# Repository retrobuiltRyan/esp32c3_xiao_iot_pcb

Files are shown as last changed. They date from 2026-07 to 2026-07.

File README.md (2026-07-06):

# esp32c3_xiao_iot_pcb
PCB for MQTT projects. Sensor, I2C screen, rotary encoder input, RGB LEDs, and buck converter breakout for the ESP32 C3 XIAO dev board.

| Project Difficulty | Rating |
|---|---|
| **Hardware Difficulty** | ●● Easy |
| **Software Complexity** | ●● Easy? | 

PCB <br>
This is the ~$5 [ESP32c3 XIAO microcontroller](https://www.digikey.com/en/products/detail/seeed-technology-co-ltd/113991054/16652880) (with its antenna on the left) variant.

P1130036

### Example Projects

Three-ish example projects are shown using this PCB:

- 1.1 – WiFi Clock
- 1.2 – Basic "Dumb" Clock
- 1.3 – Countdown Timer
- 2.0 – Weather Station with Terminal-Style Display
- 3.0 – Current (120V AC) Probe Monitor over MQTT

## 1.1 WiFi Clock
P1130023 <br>
P1130020 <br>

Large digit (70mm height) 7-segment clock. Connects to 2.4 GHz WiFi and grabs time from HTTP "google.com" TCP port 80. Previously grabbed time from NTP, but I have found some enterprise networks do not like this traffic and block the device.  

Files for the [RGB LED 7-segment digit PCB](https://github.com/retrobuiltRyan/Neo7Segment-Design-Files). You'll need to make four (each digit needs qty 29 RGB LEDs).  

A Daylight Saving Time function is implemented; however, every 6 months I find this doesn't work as expected, and 6 months between bug testing is annoying, so YMMV. DST compensation works better on Network Time Protocol grabs, but again, some networks do not like this.  

The body is 3D printed. The digit diffusion layer can be experimented with in material color and thickness. (about 0.2)

## 1.2 Dumb Clock (no WiFi)
P1130025 <br>

Same hardware, different code for a regular clock that keeps time without WiFi. Hours and minutes are set using the rotary encoder & push button.  

UI Flow:  
BOOT → SET HOURS → SET MINUTES → SET COLOR → RUN  
While in RUN → (press) BRIGHTNESS → Return  
Long press resets clock to 12:00  

## 1.3 Countdown Timer
Task Master style countdown timer. 
UI Flow:
BOOT → brightness adjust + pulsing 00:00 →press [set min] press→ [set hr] →press [start]
Time starts out green color and gradually changes to red as 00:00 time approaches.

## 2.0 Weather Station
P1130031 <br>

Calls API: https://api.weather.gov/points/40.4406,-79.9959. Then grabs weather forecast data from https://api.weather.gov/gridpoints/PBZ/78,66/forecast. A bunch of forecast data is returned in JSON text format.  The lat and long point to Pittsburgh, PA, which can be changed. This weather API is a free government service available in the USA only, one benefit is no need for API key. Code then parses only the first five forecast 'periods' to save SRAM and prints over serial (for debug) and to OLED in a terminal-style display using this [2.4 inch OLED screen](https://www.aliexpress.us/item/3256805914521312.html).  
Forecast updates every hour. 3D printed body is stylized as a classic Mac if it was extra wide.  

## 3.0 Current Probe Monitor over MQTT
P1130028 <br>
(add a dashboard pic when I get that done) <br>

It's lunchtime and you're starving, but there might be a line for the microwave and toaster! Three minutes for someone's Factor meal to cook?! Wouldn't you like to know if these appliances are available before walking to the office kitchen? What if you could check a dashboard that monitors microwave and toaster oven usage?  

Two contactless probes (current clamp) monitor current draw (0–10A) of both appliances and report their status over MQTT. A dashboard logs usage history and can provide a bunch of interesting data on office lunchtime habits. Could also be deployed as an online monitor for critical infrastructure like deep freezers or coolant pumps—useful things. A temperature and humidity sensor (SHT45) is populated on this PCB to also report ambient conditions as a baseline data point. The SHT45 is a very tiny SMD part; adding this is advanced soldering (you need that stencil ordered).

## PCB BoM
| Reference | Value | Qty | DigiKey P/N |
|---|---|----:|---|
| BZ1 | Buzzer_5V | 1 | |
| C1, C3, C4, C5, C6, C8, C10 | 0.1uF 50V | 7 | 1276-1068-1-ND |
| C2, C7, C9, C11 | 0.22uF 50V CER | 4 | 445-2283-1-ND |
| D1 | WS2812B | 1 | [aliexpress](https://www.aliexpress.us/item/3256802466699315.html) |
| D5, D6, D7 | LED | 3 | 1080-1419-1-ND |
| D8 | D | 1 | S5AC-FDICT-ND |
| D9 | SMF15A | 1 | SMF15A-E3-08CT-ND |
| J1 | Barrel_Jack 2.1 × 5.5mm | 1 | EJ508A-ND |
| J2, J5, J6, J7, J10 | Screw_Terminal_2_P3.50mm | 5 | 732-2747-ND |
| Q1 | MOSFET P-CH 30V 25A TO252 | 1 | 785-1106-1-ND |
| Q2 | MMBT2222A | 1 | MMBT2222ATPMSCT-ND |
| Q3 | AO3400A | 1 | 785-1000-1-ND |
| R1 | 220 | 1 | 311-220FRCT-ND |
| R2, R3, R5, R6 | 1K | 4 | 311-1.00KFRCT-ND |
| R4 | 3.3K | 1 | 311-3.30KFRCT-ND |
| R7 | 100k | 1 | 311-100KFRCT-ND |
| R8, R9 | 10K | 2 | 311-10.0KFRCT-ND |
| RN1 | 10k array | 1 | CAY16-103J4LFCT-ND |
| RN4 | 200 array | 1 | CAY16-201J4LFCT-ND |
| SW1 | RotaryEncoder_Switch_MP | 1 | PEC11R-4220F-S0024-ND |
| U1 | MAX40200AUK | 1 | 175-MAX40203AUK+TCT-ND |
| U2 | MP1584_Buck | 1 |[aliexpress](https://www.aliexpress.us/item/3256805684077964.html) |
| U3 | L7805 | 1 | 497-7255-1-ND |
| U7 | ESP32C3 | 1 | 1597-113991054-ND |
| U8 | UCC27511ADBV | 1 | 296-49474-1-ND |
| U9 | SHT4x | 1 | 1649-SHT45-AD1B-R2CT-ND |

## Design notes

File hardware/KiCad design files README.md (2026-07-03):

Place all three kicad files (.kicad_pcb, .kicad_sch, .kicad_pro) in a folder of the same name. Open the project file (.kicad_pro) with KiCad.
PCB

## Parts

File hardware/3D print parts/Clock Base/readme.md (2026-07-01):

3D printed body for Clock.
P1130021

print preview
P1130025

Change the z-scaling of the diffuser for the desired effect. <br>
P1130018

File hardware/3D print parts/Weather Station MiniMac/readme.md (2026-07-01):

Mac styled enclosure with a 2.4inch OLED screen.
Fasten with M2.6 x 10mm Thread forming screnws
print preview

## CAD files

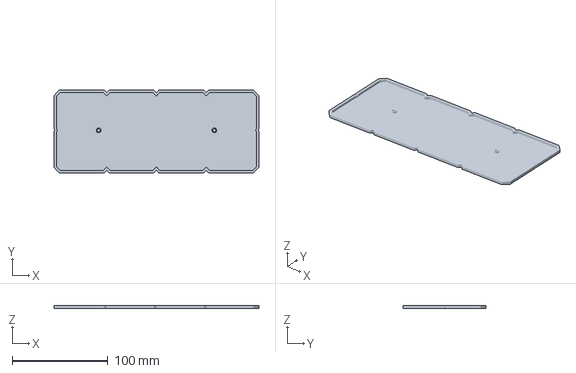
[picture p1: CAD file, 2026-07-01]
hardware/3D print parts/Clock Base/Neo7Seg_Clock cover 3of4 (thicker opacity).3MF
214.0 x 86.2 x 3.00 mm

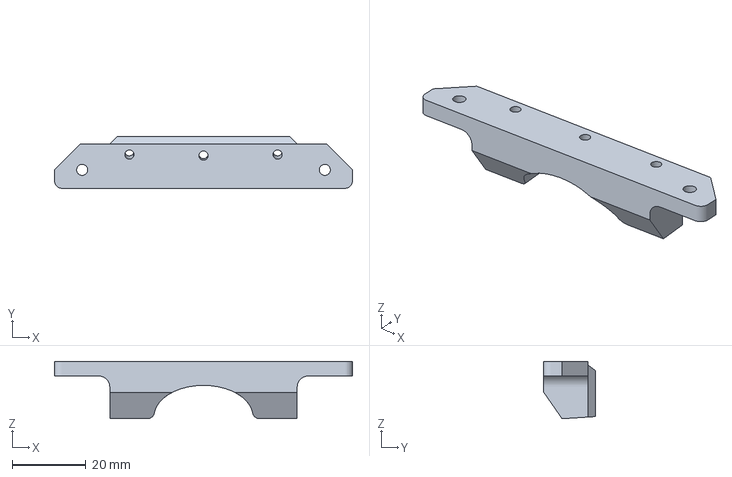
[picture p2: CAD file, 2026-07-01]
hardware/3D print parts/Weather Station MiniMac/MiniMac_Front_bracket_WIDEBOY.3MF
80.8 x 14.0 x 15.6 mm

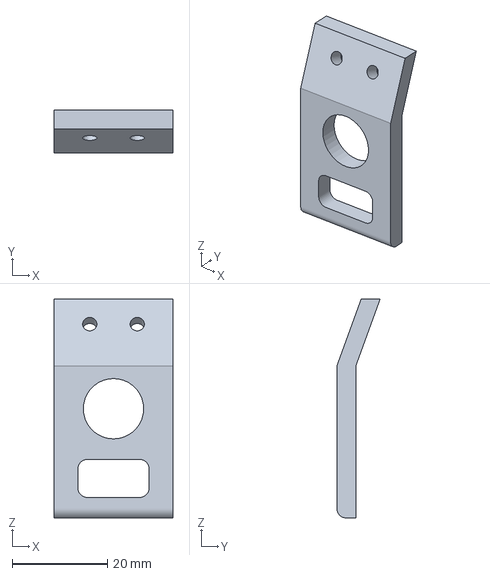
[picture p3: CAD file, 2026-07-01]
hardware/3D print parts/Clock Base/Neo7Seg_Clock leg alt 4of4.3MF
25.0 x 9.13 x 46.1 mm

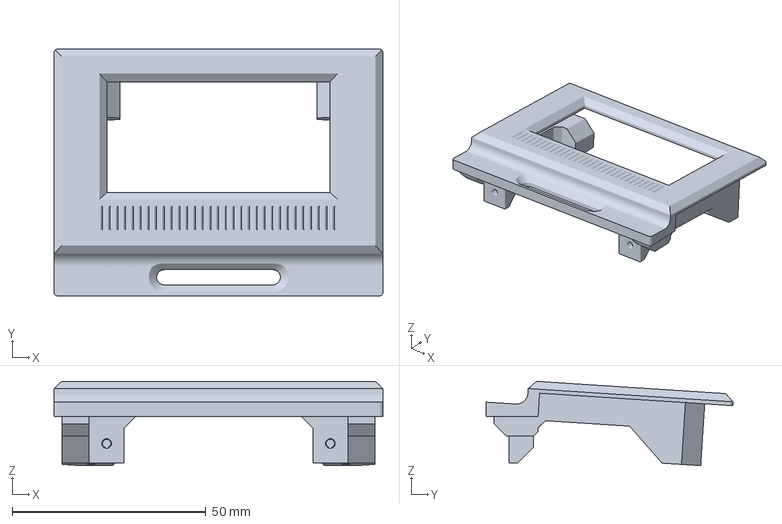
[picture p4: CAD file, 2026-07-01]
hardware/3D print parts/Weather Station MiniMac/MiniMac_Front_WIDEBOY.3MF
85.0 x 63.8 x 21.8 mm

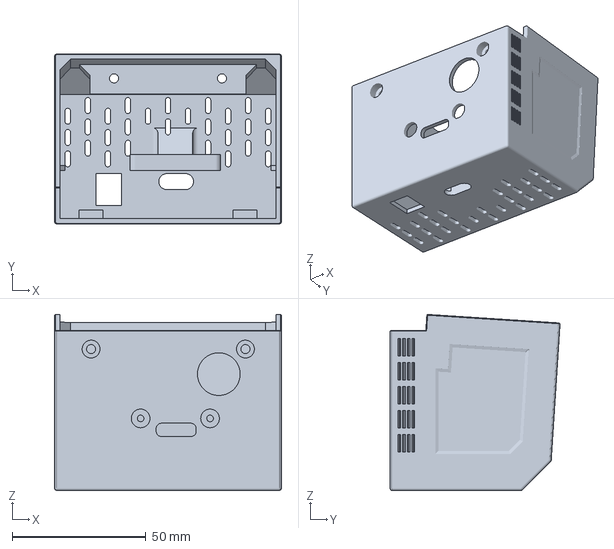
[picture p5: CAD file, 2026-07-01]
hardware/3D print parts/Weather Station MiniMac/MiniMac_Base_WIDEBOY.3MF
85.0 x 63.7 x 66.0 mm

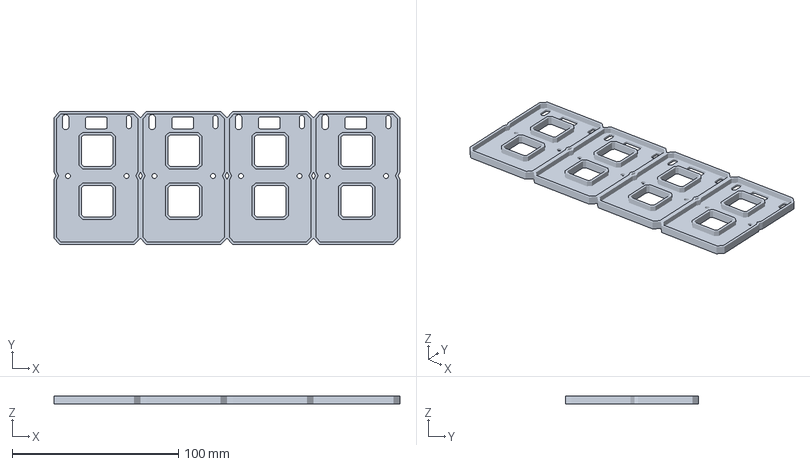
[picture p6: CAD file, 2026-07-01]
hardware/3D print parts/Clock Base/Neo7Seg_Clock Frame 1of4.3MF
208.0 x 80.2 x 5.00 mm

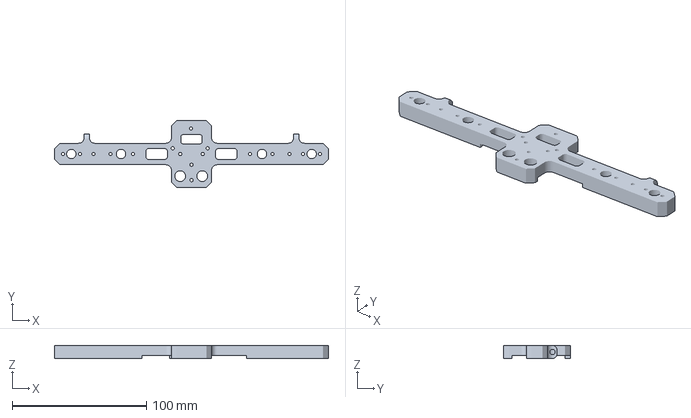
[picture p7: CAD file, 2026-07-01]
hardware/3D print parts/Clock Base/Neo7Seg_Clock rear 2of4.3MF
204.0 x 50.0 x 10.0 mm

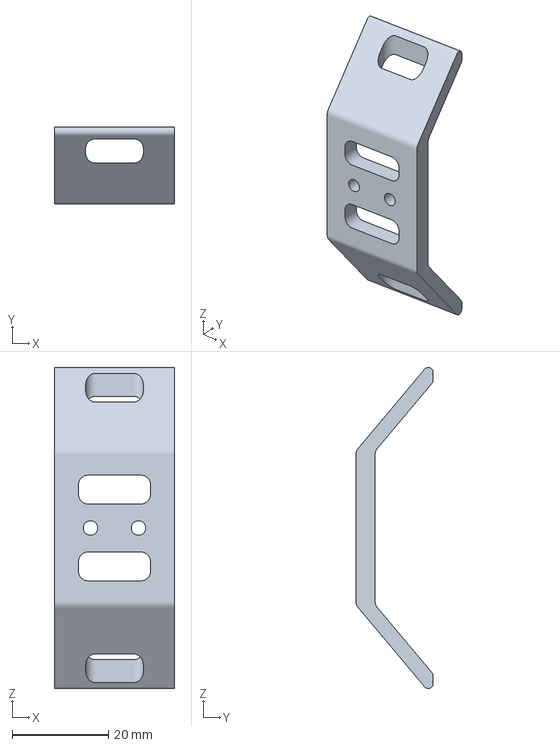
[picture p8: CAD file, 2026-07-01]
hardware/3D print parts/Clock Base/Neo7Seg_Clock leg wall 5of4.3MF
25.0 x 16.1 x 66.8 mm

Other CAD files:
hardware/3D print parts/Clock Base/Neo7Seg_Clock cover 3of4.3MF

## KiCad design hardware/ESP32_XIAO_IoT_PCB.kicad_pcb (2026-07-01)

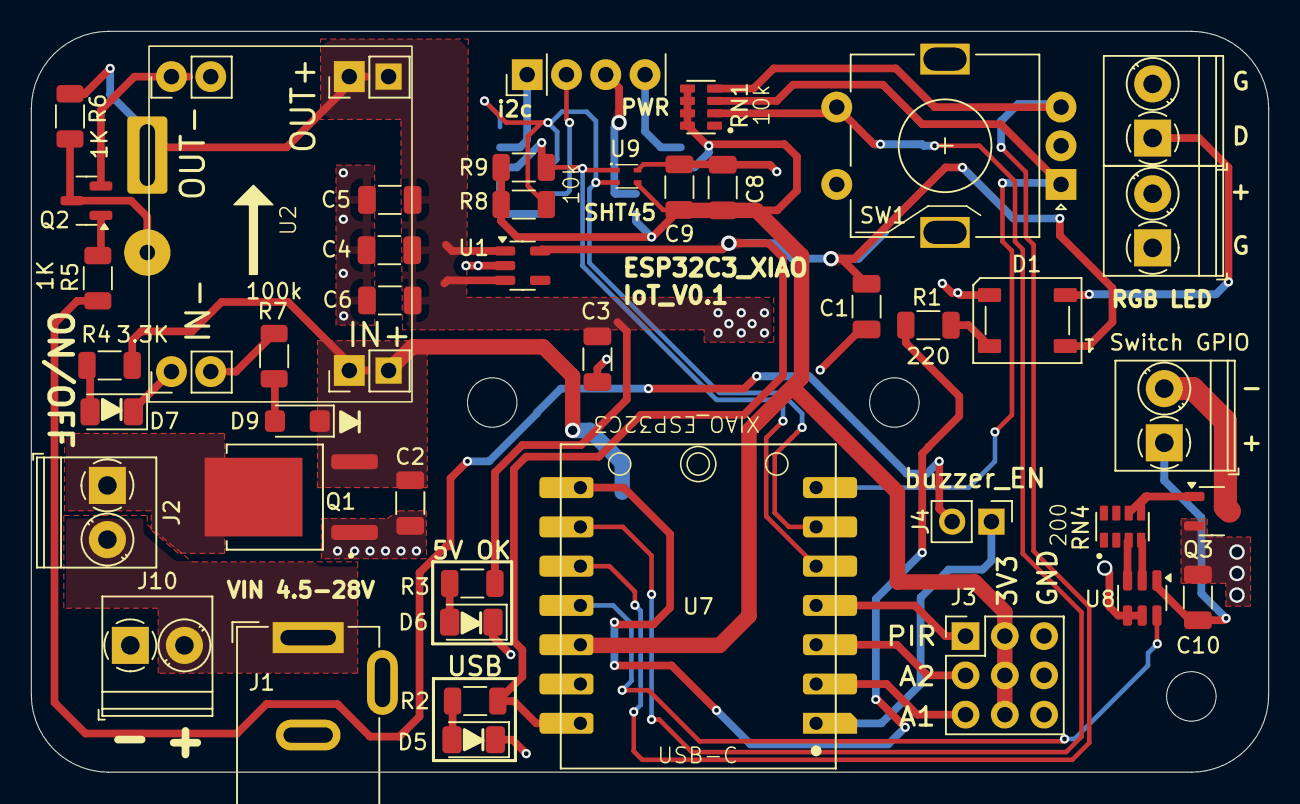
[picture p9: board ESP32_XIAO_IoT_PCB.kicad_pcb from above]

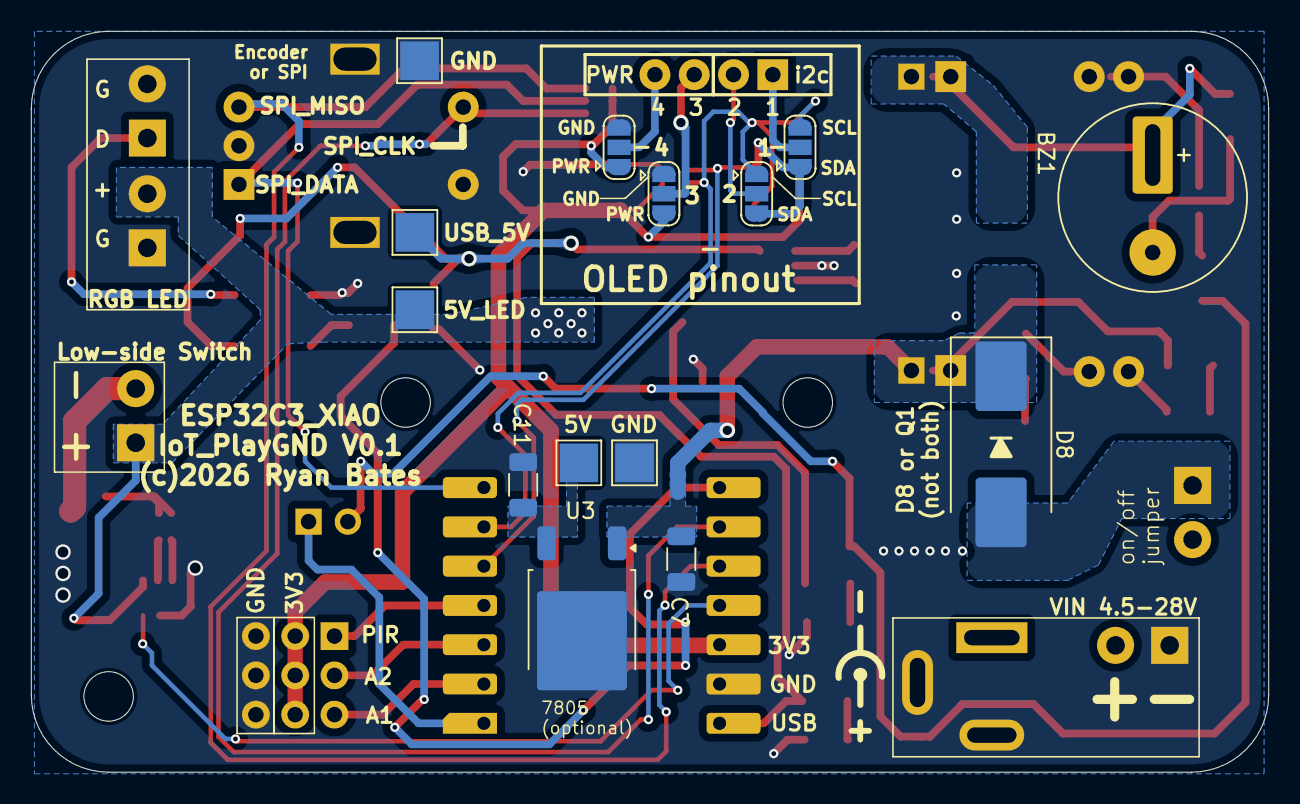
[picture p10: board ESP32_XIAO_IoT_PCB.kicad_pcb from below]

Board: 2 copper layers, 80.0 x 47.9 mm, 60 parts (14 on the bottom side), 36 nets.

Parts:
BZ1: Buzzer_5V; MagneticBuzzer_ProSignal_ABT-410-RC
C1, C3, C4, C5, C6, C8, C10: 0.1uF 50V; C_1206_3216Metric
C2, C7, C9, C11: 0.22uF 50V CER; C_1206_3216Metric
D1: WS2812B; LED_WS2812B_PLCC4_5.0x5.0mm_P3.2mm
D5, D6, D7: LED; LED_1206_3216Metric
D8: D; D_SMC_Handsoldering
D9: SMF15A; D_SMF
H1, H2, H3: MountingHole_M3; MountingHole_3.2mm_M3
J1: Barrel_Jack; BarrelJack_GCT_DCJ200-10-A_Horizontal
J2, J5, J6, J7, J10: Screw_Terminal_2_P3.50mm; TerminalBlock_Phoenix_PT-1,5-2-3.5-H_1x02_P3.50mm_Horizontal
J3: ServoPort_03; ServoPort_03_Vertical
J4: PINHD_1x2_Male; PinHeader_1x02_P2.54mm_Vertical
J9: PINHD_1x4_Male; PinHeader_1x04_P2.54mm_Vertical
JP2, JP4, JP7, JP8: SolderJumper_3_Open; SolderJumper-3_P1.3mm_Open_RoundedPad1.0x1.5mm
Q1: MOSFET P-CH 30V 25A TO252; MOSFET_P-CH_30V_25A_TO252
Q2: MMBT2222A; SOT-23
Q3: AO3400A; SOT-23-3
R1: 220; R_1206_3216Metric
R2, R3, R5, R6: 1K; R_1206_3216Metric
R4: 3.3K; R_1206_3216Metric
R7: 100k; R_1206_3216Metric
R8, R9: 10K; R_1206_3216Metric
RN1: 10k array; CAT16-4_R-Array_1206
RN4: 200 array; CAT16-4_R-Array_1206
SW1: RotaryEncoder_Switch_MP; RotaryEncoder_Alps_EC11E-Switch_Vertical_H20mm
TP2, TP3, TP4, TP5, TP6: TestPoint; TestPoint_Pad_2.5x2.5mm
U1: MAX40200AUK; SOT-23-5
U2: MP1584_Buck; MP1584
U3: L7805; TO-252-2
U7: ESP32C3; esp32c3_xiao_seeed_studio
U8: UCC27511ADBV; SOT-23-6
U9: SHT4x; SHT4X

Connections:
3V3: C8.1, C9.1, J3.VCC, JP7.3 (B), JP8.3 (B), R8.1, R9.1, RN1.5 (R4.2), RN1.6 (R3.2), RN1.7 (R2.2), RN1.8 (R1.2), U7.12 (VCC_3V3), U9.3 (VDD)
5V_LED: BZ1.1, C3.1, C4.1, C5.1, C6.1, C10.2, J6.2, J7.1, R3.1, R6.1, TP4.1, U1.1 (VDD), U1.3 (EN), U2.5 (OUT+), U2.6 (OUT+), U8.1 (V_{DD})
5V_OUT: C11.1, TP2.1, U3.3 (OUT)
+BATT: J1.1, J2.2, J10.2
/1: J9.1, JP2.2 (C)
/2: J9.2, JP4.2 (C)
/3: J9.3, JP7.2 (C)
/4: J9.4, JP8.2 (C)
/Analog1: J3.3 (IN3), U7.2 (GPIO3[D1])
/Analog2: J3.2 (IN2), U7.3 (GPIO4[D2])
/BATT_IN: D8.2 (A), J2.1, Q1.2 (S)
/BATT_IN+: C2.1, C7.1, D8.1 (K), D9.1 (A1), Q1.3 (D), R4.1, U2.3 (IN+), U2.4 (IN+), U3.1 (IN)
/Buzzer: J4.2, R5.1
/MOSFET_A_DRAIN: J7.2, Q3.3 (D)
/MOSFET_DRV_A: U7.11 (GPIO10/MOSI[D10]), U8.6 (IN+)
/PIR: J3.1 (IN1), U7.4 (GPIO5[D3])
/RGB_DATA: R1.2, U7.8 (GPIO20/RX[D7])
/SPI_CLK: RN1.2 (R2.1), SW1.S1, U7.9 (GPIO8/SCK[D8])
/SPI_DATA: RN1.3 (R3.1), SW1.A, U7.7 (GPIO21/TX[D6])
/SPI_MISO: RN1.4 (R4.1), SW1.B, U7.10 (GPIO9/MISO[D9])
/i2c+: JP2.1 (A), JP4.1 (A), R8.2, U7.6 (GPIO7/SCL[D5]), U9.2 (SCL)
/i2c-: JP2.3 (B), JP4.3 (B), R9.2, U7.5 (GPIO6/SDA[D4]), U9.1 (SDA)
GND: C1.2, C2.2, C3.2, C4.2, C5.2, C6.2, C7.2, C8.2, C9.2, C10.1, C11.2, D1.3 (VSS), D5.1 (K), D6.1 (K), D7.1 (K), J1.2 (GND), J3.GND, J5.2, J6.1, J10.1, JP7.1 (A), JP8.1 (A), Q1.1 (G), Q2.2 (E), Q3.2 (S), R7.2, SW1.C, SW1.MP, SW1.S2, TP3.1, TP5.1, U1.2 (GND), U2.1 (IN-), U2.2 (IN-), U2.7 (OUT-), U2.8 (OUT-), U3.2 (GND), U7.13 (GND), U8.4 (GND), U8.5 (IN-), U9.4 (VSS)
unnamed: D1.4 (DIN), R1.1
unnamed: D1.2 (DOUT), J5.1
unnamed: D5.2 (A), R2.2
unnamed: D6.2 (A), R3.2
unnamed: D7.2 (A), R4.2
unnamed: D9.2 (A2), R7.1
unnamed: Q2.1 (B), R5.2
unnamed: BZ1.2, Q2.3 (C), R6.2
unnamed: Q3.1 (G), RN4.5 (R4.2), RN4.6 (R3.2)
unnamed: RN4.3 (R3.1), U8.3 (OUTL)
unnamed: RN4.4 (R4.1), U8.2 (OUTH)
unnamed: J4.1, U7.1 (GPIO2[D0])
USB_5V: C1.1, D1.1 (VDD), R2.1, TP6.1, U1.5 (OUT), U7.14 (VUSB)

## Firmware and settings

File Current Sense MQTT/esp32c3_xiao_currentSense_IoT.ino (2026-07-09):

/* temp and humidity sensor, current probe (0-10A 120vAC) over MQTT, publishes a JSON formatted string to broker
prints wifi strength to json /telemtry
NOTE:A heavy trimmed down version of the ESP32-wroom iot playground board. Trimmed for a XIAO IoT board which is: Only temp sense, MqTT IoT comm, no motor drivers hardware 
The old LED and Relay functions are still present in code, but that hardware is not present, however the GPIO will still toggle via mqtt published value.

Uptime handling:
60s watchdog timer (will reboot ESP if hangs). For Wifi and MQTT connect issues. prints the reset reason over serial (not that helpful)
12hr hard reset (REBOOT_INTERVAL )

Code rev: July 7, 2026 
Hardware rev: June 4, 2025

Hardware: ESP32-C3 XIAO       digikey p/n= 1597-113991054-ND
Board: ESP32-C3 XIAO IoT
--------------------------------------------------------------------------
i2C Addresses and hardware details:
OLED                         0x3C
buck converter = 4.8V
SHT45 (temp humidity sensor) 0x44
NeoPixels 1 
---------------------------------------------------------------------------
Authors: Adafruit, Ryan Bates
Hardware: PCB=Ryan, 

*/
//Libraries used in this 
#include <WiFi.h>
#include <Adafruit_NeoPixel.h>
#include "Adafruit_MQTT.h"
#include "Adafruit_MQTT_Client.h"
#include <ArduinoJson.h>
#include "Adafruit_SHT4x.h"  // <--- SHT45 Sensor Library
#include <GyverOLED.h>
GyverOLED<SSD1306_128x64> oled; //the small 0.97" screen
//GyverOLED<SSH1106_128x64> oled; //the med 1.3" screen
#include <esp_task_wdt.h>   // <--- Added for watchdog functionality

//Current sense 
const int ACPin1 = A1;
const int ACPin2 = A2;

#define ACTECTION_RANGE 10.0
#define VREF 3.29

const float CAL_FACTOR_1 = 0.97865; 
const float CAL_FACTOR_2 = 0.97610;

float probe1 = 0.0;
float probe2 = 0.0;

// -----------------------------------------------------
// Read AC current from a given analog pin
// -----------------------------------------------------
float readACCurrentValue(int analogPin)
{
  float adcSum = 0;

  // Average ADC samples
  for (int i = 0; i < 100; i++)
  {
    adcSum += analogRead(analogPin);
    delay(1);
  }

  float adcAvg = adcSum / 100.0;

  // Convert ADC -> "virtual RMS-ish voltage"
  float voltageVirtualValue = adcAvg * 0.707;

  // Convert ADC counts to volts, then account for divider/amplifier
  voltageVirtualValue = (voltageVirtualValue / 4096.0 * VREF) / 2.0;

  // Convert voltage to current
  float current = voltageVirtualValue * ACTECTION_RANGE;

  return current;
}

// Which pin on the Arduino is connected to the NeoPixels?
#define LED_PIN    20

// How many NeoPixels are attached to the Arduino?
#define LED_COUNT 1

// Declare our NeoPixel strip object:
Adafruit_NeoPixel pixels(LED_COUNT, LED_PIN, NEO_GRB + NEO_KHZ800);

#define LEDpin 2 
#define RELAY1pin 3
String LEDpin_status = "OFF";

//************************12hr reboot**********************************/
#define REBOOT_INTERVAL 43200000UL  // 12 hours in milliseconds
unsigned long lastRebootCheck = 0;

/************************* WiFi Access Point **************************/
#define WLAN_SSID       "" //your wifi IF
#define WLAN_PASS       ""// your password

/************************* MQTT Broker Setup **************************/
#define AIO_SERVER      ""
#define AIO_SERVERPORT  
#define AIO_USERNAME    ""
#define AIO_KEY         ""

//************************MQTT feeds and topics setup*******************/
WiFiClient client;
Adafruit_MQTT_Client mqtt(&client, AIO_SERVER, AIO_SERVERPORT, AIO_USERNAME, AIO_KEY);

//direct publish data (this is mostly a redundant section when you see the json telemetry string).
Adafruit_MQTT_Publish Temperature = Adafruit_MQTT_Publish(&mqtt, AIO_USERNAME "/feeds/serverroom/temperature");
Adafruit_MQTT_Publish Humidity = Adafruit_MQTT_Publish(&mqtt, AIO_USERNAME "/feeds/serverroom/humidity");
Adafruit_MQTT_Publish Voltage = Adafruit_MQTT_Publish(&mqtt, AIO_USERNAME "/feeds/kitchen/deviceBattery"); //this hardware is not present
Adafruit_MQTT_Publish Amp_Probe_1 = Adafruit_MQTT_Publish(&mqtt, AIO_USERNAME "/feeds/serverroom/currentprobe1"); 
Adafruit_MQTT_Publish Amp_Probe_2 = Adafruit_MQTT_Publish(&mqtt, AIO_USERNAME "/feeds/serverroom/currentprobe2"); 

//you can publish to theses topics via MQTTX... see code that controls hardware
Adafruit_MQTT_Subscribe onoffbutton = Adafruit_MQTT_Subscribe(&mqtt, AIO_USERNAME "/feeds/kitchen/LEDpin");
Adafruit_MQTT_Subscribe RELAY1 = Adafruit_MQTT_Subscribe(&mqtt, AIO_USERNAME "/feeds/kitchen/RELAY1pin");


#define CLIENT_TELEMETRY_TOPIC AIO_USERNAME "/feeds/serverroom/telemetry"


//*************************Tempurature sensor setup***********************/
Adafruit_SHT4x sht4 = Adafruit_SHT4x();  // <--- SHT45 object
float tempC = 0.0;
float humid = 0.0;


void setup() {
  delay(100);
  pixels.setPixelColor(0, pixels.Color(50, 0, 0)); //Sets RGB values from 0 (off) to 255 (max) brightness
  pixels.show(); 
  delay(1000); //short pause to show a red status and initalizing

  oled.init(); oled.clear(); oled.setScale(1); //1 is small, 4 is huge 
  oled.setCursorXY(0, 0); 
  oled.print(" ESP32-C3 XIAO IoT");
  oled.update();

  pixels.begin(); // INITIALIZE NeoPixel strip object (REQUIRED)
  pixels.clear(); // Set all pixel colors to 'off'

  Serial.begin(115200);
  // Wait until serial port is opened
  //while (!Serial) { delay(10); }


  pinMode(LEDpin, OUTPUT);
  pinMode(RELAY1pin, OUTPUT);

  // Get MAC address and print it
  String mac = WiFi.macAddress();
  Serial.print("ESP32 MAC Address: ");
  Serial.println(mac);
  oled.setCursorXY(0,26);
  oled.print("MAC "); oled.print(mac); 
  oled.rect(0, 9, 127, 10);  // a 1-pixel tall rectangle
  oled.update();

  Serial.println("Connecting to WiFi...");
  WiFi.begin(WLAN_SSID, WLAN_PASS);
  while (WiFi.status() != WL_CONNECTED) {
    delay(500);
    Serial.print(".");
  }
  Serial.println("\nWiFi connected. IP address: " + WiFi.localIP().toString());
  oled.setCursorXY(0,14);
  oled.print("WiFi@ " + WiFi.localIP().toString() );
  oled.update();
  pixels.setPixelColor(0, pixels.Color(10, 10, 0)); //Sets RGB values from 0 (off) to 255 (max) brightness
  pixels.show();  //go yellow light after wifi is connected

  mqtt.subscribe(&onoffbutton);
  mqtt.subscribe(&RELAY1);

  // Initialize SHT45 sensor
  Serial.println("Initializing SHT4x...");
  if (!sht4.begin()) {
    Serial.println("Couldn't find SHT4x");
    while (1) delay(10);
  }
//temp and humidity accuracy/ power/ read time. pick only one
  //sht4.setPrecision(SHT4X_HIGH_PRECISION);
  sht4.setPrecision(SHT4X_MED_PRECISION);
  //sht4.setPrecision(SHT4X_LOW_PRECISION);

  sht4.setHeater(SHT4X_NO_HEATER);
  // a built-in resistive heater can turn on temporarily to warm the sensor, Evaporate condensation....
  Serial.println("SHT4x sensor ready.");



  // ===== Watchdog setup (added) =====
  esp_task_wdt_init(60, true);    // 60 sec timeout, auto-reset if not fed
  esp_task_wdt_add(NULL);         // Add main loop task to watchdog
  Serial.println("Watchdog initialized (60s timeout)");
}

uint32_t x = 0, y = 0; //counters to track how many times 
//temperature (x) and humidity (y) values are published to the MQTT broker 

void loop() {
  esp_task_wdt_reset();  // feed watchdog at start of loop

  // ===== WiFi Reconnect Check =====
  if (WiFi.status() != WL_CONNECTED) {
    Serial.println("WiFi disconnected, reconnecting...");
    WiFi.disconnect();
    WiFi.begin(WLAN_SSID, WLAN_PASS);
    unsigned long startAttemptTime = millis();

    // try for 10s max
    while (WiFi.status() != WL_CONNECTED && millis() - startAttemptTime < 10000) {
      delay(500);
      Serial.print(".");
      esp_task_wdt_reset();   // feed watchdog during reconnect loop
    }
    if (WiFi.status() == WL_CONNECTED) {
      Serial.println("\nReconnected to WiFi, IP: " + WiFi.localIP().toString());
    } else {
      Serial.println("\nWiFi reconnect failed.");
    }
  }

    currentSenseRead();  //get the current probe values


  // ===== MQTT Reconnect Check =====
  if (!mqtt.connected()) {
    Serial.println("MQTT disconnected, reconnecting...");
    MQTT_connect();   // your existing connection handler
  }

  // ===== Keep MQTT alive =====
  mqtt.processPackets(10);  // non-blocking subscription handling
  mqtt.ping();              // keeps broker connection alive

  get_SHT45_data();         // Read SHT45 data
  json_telemetry();         // Package and send telemetry
  esp_task_wdt_reset();     // feed after telemetry work

//=====================Hardware Toggle Capable topics==================================================================================
//if published topics match these checks, do something with the hardware
  Adafruit_MQTT_Subscribe *subscription; //check for telemetry subscription data (5sec) sent to the ESP
  while ((subscription = mqtt.readSubscription(5000))) {
    esp_task_wdt_reset(); // feed watchdog while waiting for subscriptions
    if (subscription == &onoffbutton) {
      if (strcmp((char *)onoffbutton.lastread, "1") == 0) {
        digitalWrite(LEDpin, HIGH);
        Serial.println("LED ON");
      } else {
        digitalWrite(LEDpin, LOW);
        Serial.println("LED OFF");
      }
    }

    if (subscription == &RELAY1) {
      if (strcmp((char *)RELAY1.lastread, "1") == 0) {
        digitalWrite(RELAY1pin, HIGH);
        Serial.println("Relay ON");
      } else {
        digitalWrite(RELAY1pin, LOW);
        Serial.println("Relay OFF");
      }
    }
  }
//==============block that publishes the solo temp data=========================
  Serial.print("\nPublishing temperature... ");
  if (!Temperature.publish(tempC)) {
    Serial.println("Failed");
  } else {
    Serial.println("OK");
    x++;
  }
//==============block that publishes the solo humidity data=========================
  Serial.print("Publishing humidity... ");
  if (!Humidity.publish(humid)) {
    Serial.println("Failed");
  } else {
    Serial.println("OK");
    y++;
  }




  esp_task_wdt_reset();  // final feed before next loop iteration





// ================================== 12-Hour Auto Reboot ================================
if (millis() - lastRebootCheck > REBOOT_INTERVAL) {
  Serial.println("\n=== 12-HOUR AUTO REBOOT INITIATED ===");
  delay(1000);
  ESP.restart();   // perform a clean system reboot
}


}

void currentSenseRead(){
  probe1 = readACCurrentValue(ACPin1) * CAL_FACTOR_1;
  probe2 = readACCurrentValue(ACPin2) * CAL_FACTOR_2;

  Serial.print("P1: ");
  Serial.print(probe1, 2);
  Serial.print(" A   P2: ");
  Serial.print(probe2, 2);
  Serial.println(" A");

  //screenUpdate(probe1, probe2);
}

// === SHT45 Sensor Reading ===
void get_SHT45_data() {
  sensors_event_t humidity_event, temp_event;
  uint32_t timestamp = millis();

  sht4.getEvent(&humidity_event, &temp_event);
  timestamp = millis() - timestamp;

  tempC = temp_event.temperature;
  humid = humidity_event.relative_humidity;

  Serial.print("Temperature: "); Serial.print(tempC); Serial.println(" °C");
  Serial.print("Humidity: "); Serial.print(humid); Serial.println(" %");
  Serial.print("Read duration (ms): "); Serial.println(timestamp);

  oled.setCursorXY(0,40);
  oled.print(tempC); oled.print(" C  ");
  oled.print(humid); oled.print(" % H");
  oled.setCursorXY(0,50); 
  oled.print("P1:"); oled.print(probe1,2); oled.print("A  ");
  oled.print("P2:"); oled.print(probe2,2); oled.print("A");
  oled.update();
}

// === Telemetry JSON Pack + Publish ===
void json_telemetry() {
  LEDpin_status = digitalRead(LEDpin) ? "ON" : "OFF";

  DynamicJsonDocument doc(1024);
  //doc["sensorType"] = "SHT45";
  doc["Location"] = "Kitchen";
  doc["temperature"] = tempC;
  doc["humidity"] = humid;
  doc["currentprobe1"] = probe1;
  doc["currentprobe2"] = probe2;
  doc["uptime"] = (millis() / 1000);
  //doc["LEDpinStatus"] = LEDpin_status;
  //doc["RelayPinStatus"] = digitalRead(RELAY1pin);
  

  // === WiFi Signal Information ===
  int rssi = WiFi.RSSI();  // dBm value
  int wifiStrength = constrain(map(rssi, -90, -30, 0, 100), 0, 100);
  doc["AV WiFi RSSI (dBm)"] = rssi;          // e.g. -67 [-45 = very strong, -80 = weak]
  doc["AV WiFi Signal (%)"] = wifiStrength;  // e.g. 75%

  // add more data strings here

  String telemetry;
  serializeJson(doc, telemetry);
  Serial.print("Sending telemetry: ");
  Serial.println(telemetry);

  if (!mqtt.publish(CLIENT_TELEMETRY_TOPIC, telemetry.c_str())) {
    Serial.println("Failed to send telemetry");
  } else {
    Serial.println("Telemetry sent successfully");
  }
}


// === MQTT Connection Handler ===
void MQTT_connect() {
  int8_t ret;

  if (mqtt.connected()) return;

  Serial.print("Connecting to MQTT... ");
  uint8_t retries = 3;
  while ((ret = mqtt.connect()) != 0) {
    Serial.print("Failed, code: ");
    Serial.println(mqtt.connectErrorString(ret));
    mqtt.disconnect();
    delay(5000);
    esp_task_wdt_reset();   // feed watchdog during retry delays
    if (--retries == 0) {
      Serial.println("Giving up on MQTT.");
      while (1);
    }
  }
  Serial.println("MQTT connected!");

  pixels.setPixelColor(0, pixels.Color(0, 20, 0)); //Sets RGB values from 0 (off) to 255 (max) brightness
  pixels.show(); //go green led status if MQTT is connected

}


//built from the Adafruit MQTT library example
/***********************************************************************
  Adafruit MQTT Library ESP32 Adafruit IO SSL/TLS example

  Use the latest version of the ESP32 Arduino Core:
    https://github.com/espressif/arduino-esp32

  Works great with Adafruit Huzzah32 Feather and Breakout Board:
    https://www.adafruit.com/product/3405
    https://www.adafruit.com/products/4172

  Adafruit invests time and resources providing this open source code,
  please support Adafruit and open-source hardware by purchasing
  products from Adafruit!

  Written by Tony DiCola for Adafruit Industries.
  Modified by Brent Rubell for Adafruit Industries
  MIT license, all text above must be included in any redistribution
 **********************************************************************/

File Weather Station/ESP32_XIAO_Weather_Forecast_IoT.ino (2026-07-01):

```cpp
//Weather forcast dashboard json data edge device
//Hardware: ESP32-C3 XIAO + Custom PCB.
//Board Manager ID: XIAO_ESP32C3 (if com fails 'error status 2' you need to press on XIAO Boot+resert then release Reset>boot))
// Flash Memory 4MB 
// SRAM 400KB

/* calls API "https://api.weather.gov/points/40.4406,-79.9959"
Then grabs weather forecast data from https://api.weather.gov/gridpoints/PBZ/78,66/forecast
parses only the first five 'periods' to save SRAM and prints over serial and OLED.
Forecast updates every hour. 
Also grabs the time over NTP (time.h) ****need to fix this, it will get booted off enterprise networks
RGB_LEDs turn on for extra razzle-dazzle
Code:  rev: Feb  7, 2026
 + hardware
--------------------------------------------------------------------------
API things to know
day-day forcast summary: 
https://api.weather.gov/gridpoints/PBZ/78,66/forecast

detailed plottable temp, wind, percip%:
https://api.weather.gov/gridpoints/PBZ/78,66

--------------------------------------------------------------------------
i2C Addresses and hardware details:
OLED                         0x3C
---------------------------------------------------------------------------
Authors: Ryan,
Hardware: 
*/

// ======================= To DO ==========================
// remove the NTP sync. is blockable on entreprise networks
// =======================================================================
#include <WiFi.h>
#include <WiFiClientSecure.h>
#include <Adafruit_NeoPixel.h>
#include <ArduinoJson.h>
#include <Wire.h>
#include <GyverOLED.h>
#include <time.h>  // <-- Include time functions

//============NeoPixel Setup============================================
// Which pin on the Arduino is connected to the NeoPixels?
#define LED_PIN    20   // ESP32-C3 CHANGE (safe GPIO on XIAO)
// How many NeoPixels are attached to the Arduino?
#define LED_COUNT 1
// Declare our NeoPixel strip object:
Adafruit_NeoPixel pixels(LED_COUNT, LED_PIN, NEO_GRB + NEO_KHZ800);

// Built-in LED
#define LEDpin 21   // ESP32-C3 CHANGE (XIAO onboard LED)

// OLED setup
GyverOLED<SSD1306_128x64, OLED_BUFFER> oled;
//GyverOLED<SSD1306_128x64, OLED_NO_BUFFER> oled; //the big screen

// =========================== WiFi Config =============================
const char* ssid = "";   // your SSID
const char* password = ""; // your password

// =========================== Weather API Config =============================
const char* host = "api.weather.gov";
const int httpsPort = 443;
WiFiClientSecure client;

// =========================== Globals =============================
unsigned long lastFetch = 0;
const unsigned long interval = 3600000; // 1 hour

// ===================== Forecast Display Config (NEW) =====================
#define MAX_PERIODS 5           //how many days or chunks of forecast data to collect (biggest culprit of DRAM usage)
#define FORECAST_DELAY_MS 6000   // <-- adjust per-forecast screen delay

#define OLED_COLS 21   // approx chars per line @ scale 1
#define OLED_ROWS 8

struct ForecastPeriod {
  String name;
  String text;
  int precip;      // probability %
  int temperature; // optional, useful later
  int windSpeed;     // mph (numeric)
};

ForecastPeriod forecasts[MAX_PERIODS];
int forecastCount = 0;
int currentPeriod = 0;

// Timezone offset (e.g. UTC-5 hours for EST)
const long gmtOffset_sec = -5 * 3600;
const int daylightOffset_sec = 3600;  // 1 hour daylight saving

const static uint8_t icons_rain_8x8[][8] PROGMEM = {
  {0x10, 0x38, 0x7C, 0x7C, 0x38, 0x10, 0x28, 0x10}  // rain drop 🌧️
  // Explanation:
  // 0x10 = 00010000    -> top point of drop
  // 0x38 = 00111000    -> upper curve
  // 0x7C = 01111100    -> middle wide
  // 0x7C = 01111100
  // 0x38 = 00111000
  // 0x10 = 00010000    -> bottom point
  // 0x28 = 00101000    -> tiny rain trail
  // 0x10 = 00010000    -> final point of trail
};


void setup() {
  // ESP32-C3 explicit I2C pins (XIAO defaults)
  Wire.begin(); 

  Serial.begin(115200);
  pinMode(LEDpin, OUTPUT);
  delay(100);

  String mac = WiFi.macAddress();
  Serial.print("ESP32 MAC Address: ");
  Serial.println(mac);

  pixels.begin();           // INITIALIZE NeoPixel strip object (REQUIRED)
  pixels.clear(); // Set all pixel colors to 'off'

  pixels.setPixelColor(0, pixels.Color(10, 0, 0));
  pixels.setPixelColor(1, pixels.Color(0, 10, 0));
  pixels.setPixelColor(2, pixels.Color(5, 5, 0));
  pixels.setPixelColor(3, pixels.Color(0, 0, 10));
  pixels.show(); 

  oled.init();
  oled.setContrast(255);
  oled.setScale(1);
  oled.clear();
  oled.setCursor(0, 0);
  oled.print("Connecting...");
  oled.update();

  WiFi.begin(ssid, password);
  Serial.print("Connecting to WiFi");
  while (WiFi.status() != WL_CONNECTED) {
    delay(500);
    Serial.print(".");
  }

  Serial.println("\n✅ Connected to WiFi!");
  oled.clear();
  Serial.println("\nWiFi connected. IP address: " + WiFi.localIP().toString());
  oled.setCursorXY(0,16);
  oled.print("WiFi@ " + WiFi.localIP().toString() );
  oled.update();

  oled.setCursorXY(0,28);
  oled.print("MAC "); oled.print(mac); 
  oled.rect(0, 9, 127, 10);
  oled.setCursorXY(0,40); oled.print("Fetching forecast..");
  oled.update();

  client.setInsecure(); // Disable certificate validation

  // ====== Setup NTP time sync =======
  configTime(gmtOffset_sec, daylightOffset_sec, "pool.ntp.org", "time.nist.gov");
  Serial.println("Waiting for time synchronization...");
  oled.setCursor(0, 26);
  oled.print("Fetching NTP Time...");
  oled.update();

  struct tm timeinfo;
  while (!getLocalTime(&timeinfo)) {
    delay(500);
    Serial.print(".");
    oled.print(".");
    oled.update();
  }
  Serial.println("\nTime synchronized!");

  fetchForecast();  // Initial forecast
}

// =============== New function to show current time on OLED ===============
void showCurrentTime() {
  struct tm timeinfo;
  oled.setScale(1);
  if (getLocalTime(&timeinfo)) {
    digitalWrite(LEDpin, HIGH);
    oled.clear();
    oled.setCursor(0, 0);
    oled.print("Time:");
    oled.setCursor(0, 2);
    char timeStr[20];
    strftime(timeStr, sizeof(timeStr), "%Y-%m-%d", &timeinfo);
    oled.print(timeStr);
    oled.setCursor(0, 4);
    strftime(timeStr, sizeof(timeStr), "%H:%M:%S", &timeinfo);
    oled.print(timeStr);
    oled.update();
  } else {
    oled.clear();
    oled.setCursor(0, 0);
    oled.print("Time not");
    oled.setCursor(0, 2);
    oled.print("available");
    oled.update();
  }
  delay(350);
  digitalWrite(LEDpin, LOW);
}
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

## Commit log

2026-07-01 Update and rename .gitkeep to KiCad design files
2026-07-01 kicad design files rev feb 2026
    [ESP32_XIAO_IoT_PCB.kicad_pcb, ESP32_XIAO_IoT_PCB.kicad_sch]
2026-07-01 Update and rename esp32c3_xiao_Neo7segment_clock_HTTP_sync.txt to esp32c3_xiao_Neo7segment_clock_HTTP_sync.ino
    change for markdown format
2026-07-01 Update and rename KiCad design files to KiCad design files.md
2026-07-03 Rename KiCad design files.md to KiCad design files README.md
2026-07-03 Update KiCad design files README.md
2026-07-09 Update esp32c3_xiao_currentSense_IoT.ino
    changed oled printout to probe#2 value (was duplicate probe1)

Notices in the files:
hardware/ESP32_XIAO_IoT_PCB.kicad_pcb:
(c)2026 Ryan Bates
